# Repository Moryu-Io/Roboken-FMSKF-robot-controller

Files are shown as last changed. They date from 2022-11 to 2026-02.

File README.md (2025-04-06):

# Roboken-FMSKF-robot-controller
## 概要
Teensy4.1を使用した新ROBO-剣出場ロボット[Quinque](https://www.robo-one.com/rankings/view/1127)のHW制御統括マイコンFW  
主な役割は以下
- Ethernet経由Micro-ROSで、ロボット全体を統括する上位LinuxPCと情報をやり取りする
- 5軸ロボットアームへの指示、情報収集
- 4輪メカナムホイールモータの速度制御
- 距離センサを用いて床や相手ロボットの検知を簡易的に行う
- 相手ロボット認識用のカメラをPan/Tiltさせるサーボモータを制御

## SW構成(src内)
すべてFreeRTOSのタスクベースでフォルダ分け

| フォルダ名 | 説明 |
| --- | --- |
|RobotManager|Ethernet経由Micro-ROSで、上位のLinuxPCと情報をやり取りしながらHW行動を決定するモジュール|
|ArmDrive|5軸ロボットアームの制御を行う。各関節ごとに[ドライバ](https://github.com/Moryu-Io/Bldc_Servo_Driver_Prj)内で位置/トルク制御を行うため、このモジュールでは指示を統括|
|VehicleDrive|4輪メカナムホイールのモータ制御を行う。こちらはDJIのM2006,C610を使用しており、ドライバ内でのトルク制御を行うため、モータの速度制御から上位の指示/制御を統括|
|FloorDetect|競技エリアから落ちないように距離センサで床面をセンシングするモジュール|
|CameraGimbal|カメラをPan/Tiltさせる汎用サーボモータの制御モジュール|
|Logger|Print文をSDカードに保存するためのDebug用モジュール|
|Debug|DebugPrintやRTOSのリソース状況を出力するDebug用モジュール|
|Utility|汎用モジュール。自作の計算処理など|

## 使用ライブラリ
| フォルダ名 | 説明 |
| --- | --- |
|[FreeRTOS-Teensy4](https://github.com/juliandesvignes/FreeRTOS-Teensy4)|RTOS|
|[micro_ros_arduino](https://github.com/micro-ROS/micro_ros_arduino)|Micro-ROS Quinque用のカスタムメッセージを含めてビルドしたものを同梱|
|[IcsClass_V210](https://kondo-robot.com/faq/ics-library-a2)|一部使用している近藤科学製サーボモータ制御用|
|[TsyDMASPI](https://github.com/hideakitai/TsyDMASPI)|IMU用SPIだが現状ほぼ未使用|

# 雑多なメモ
## 新規Msgの追加方法
### msgファイルの作成

`micro_ros_arduino\extras\library_generation\extra_packages`直下にmsgフォルダを作る

[公式チュートリアル](https://micro.ros.org/docs/tutorials/advanced/create_new_type/)に従って、.msgファイルの作成とCMakeLists.txtへの登録を行う

ここには記載がないが、package.xml末尾に以下を追加する必要もある
```
  <build_depend>rosidl_default_generators</build_depend>
  <exec_depend>rosidl_default_runtime</exec_depend>
  <member_of_group>rosidl_interface_packages</member_of_group>
```

### micro_ros_arduinoライブラリを作成する
wsl2にて以下のコマンドを発行
```
sudo service docker start

docker pull microros/micro_ros_static_library_builder:foxy
docker run -it --rm -v $(pwd):/project --env MICROROS_LIBRARY_FOLDER=extras microros/micro_ros_static_library_builder:foxy -p teensy4
```
※2022/05/08 wsl2で上記コマンドでdocker使用時に名前解決ができなくなっていた。原因不明。

[このサイト](https://qiita.com/takkeybook/items/37af683bfb1a4eca6aa2)に従って、`/etc/resolv.conf`に記載のDNSサーバーを変更する

### PC側での準備
通信するPC側では同様のmsg定義フォルダを作成
```
colcon build --symlink-install --packages-up-to interfaces
. install/local_setup.bash
ros2 run micro_ros_agent micro_ros_agent udp4 -p 9999
```

### Micro-ROSテスト方法memo
- topic
```
ros2 topic echo /VehicleInfo
```

- service
```
ros2 service call /ProcStatus interfaces/srv/ProcStatus "{id: 1}"
```

## FreeRTOS

こちらのリポジトリをベースに、libフォルダに格納
https://github.com/juliandesvignes/FreeRTOS-Teensy4

変更点
* heap3からheap4に
    * heap3はC言語のmallocなどのラッパだが、Teensyduinoではmallocで確保されるのは通常RAM。
    * heap4でucHeapをTCMに配置することで高速性を担保
* 別途configファイルを設定

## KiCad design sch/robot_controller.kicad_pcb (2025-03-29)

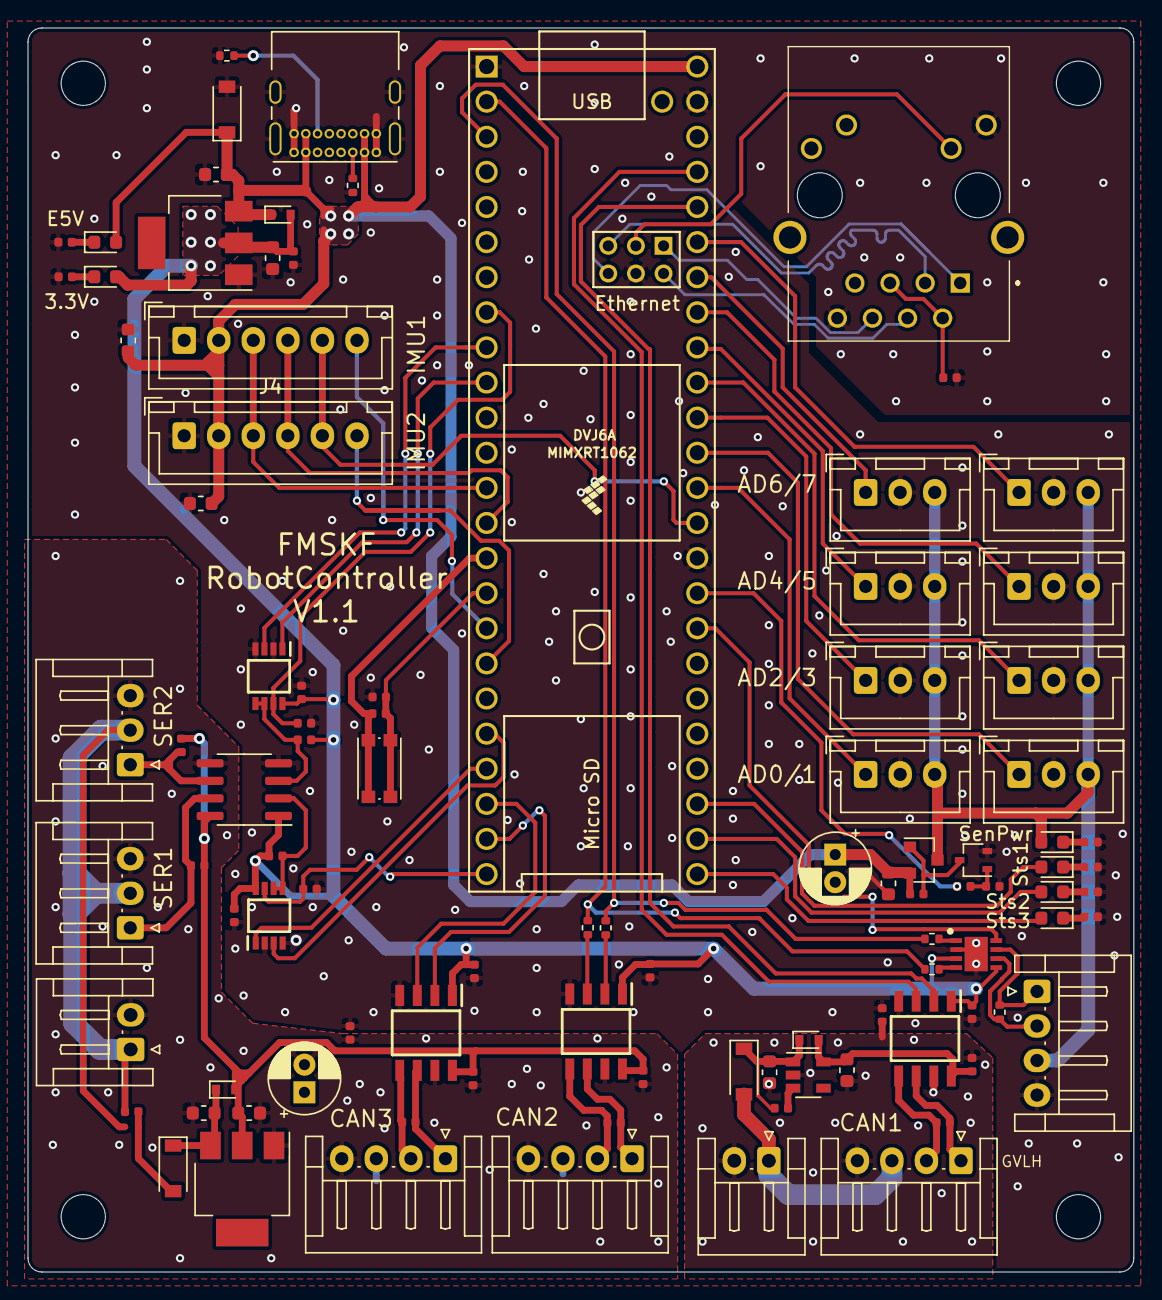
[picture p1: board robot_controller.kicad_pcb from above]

Board: 2 copper layers, 80.0 x 90.0 mm, 102 parts (0 on the bottom side), 78 nets.

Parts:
C1, C3, C17, C19, C21: 1u; C_0603_1608Metric
C2, C4, C8, C11, C12, C13, C14, C15, C16, C18, C20: 0.1u; C_0402_1005Metric
C5, C6, C7, C22: 10u; C_0603_1608Metric
C24, C25: 47u; CP_Radial_D5.0mm_P2.00mm
D1, D7, D11: PMEG6010CEGWJ; D_SOD-123
D2, D4, D6, D13, D14, D15: LED; LED_0603_1608Metric
D5, D9, D12: RB5105SM-40T; D_SOD-523
H1, H2, H3, H4: MountingHole; MountingHole_3.2mm_M3
IC1, IC2, IC5: ISO1044BDR; SOIC127P600X175-8N
IC3, IC4: 74LVC2G125DP,125; SOP65P400X110-8N
IC6: TLT9251VLEXUMA1; SON65P300X300X110-9N
J1: USB_C_Receptacle_USB2.0; USB_C_Receptacle_GCT_USB4085
J2, J4: Conn_01x06; JST_XH_B6B-XH-A_1x06_P2.50mm_Vertical
J3: RJ45_LED; J1B1211CCD
J5, J6, J7, J8, J9, J10, J11, J12: Conn_01x03; JST_XH_B3B-XH-A_1x03_P2.50mm_Vertical
J13, J15, J17, J18: Conn_01x04; JST_EH_S4B-EH_1x04_P2.50mm_Horizontal
J16, J20: Conn_01x02; JST_EH_S2B-EH_1x02_P2.50mm_Horizontal
J19, J21: Conn_01x03; JST_EH_S3B-EH_1x03_P2.50mm_Horizontal
Q2: 2SC4116; SOT-323_SC-70
Q4: IRLML6402; SOT-23
R1, R10, R12, R14, R23, R24, R27, R28, R31, R36, R37: 10k; R_0402_1005Metric
R2, R5: 5.1k; R_0402_1005Metric
R3, R16, R22, R38, R39, R40: 1k; R_0402_1005Metric
R4, R6, R8, R9, R25, R26, R33: 0; R_0402_1005Metric
R7, R29, R30, R35: 60; R_0402_1005Metric
SW1: SW_SPST; SW_Push_1P1T_NO_CK_KMR2
U1: Teensy4.1; Teensy41simple_onlyeth
U2: AZ1117-3.3; SOT-223
U3: ISO1540; SOIC-8_3.9x4.9mm_P1.27mm
U4: NCP718xSN500; SOT-23-5
U5: LD1117S50TR_SOT223; SOT-223-3_TabPin2

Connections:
+3.3VP: C7.1, C8.1, C11.1, C12.1, C13.1, C14.1, C18.1, D5.2, D6.2, IC1.1, IC2.1, IC3.8, IC4.8, IC5.1, IC6.3, IC6.5, R27.1, R28.1, U2.2, U3.1
+3V3: C4.1, SW1.1, U1.15, U1.46
+5VL: C1.1, C3.1, C5.1, C6.1, C24.1, D1.1, D2.2, D5.1, J1.A4, J1.A9, J1.B4, J1.B9, J2.2, J4.2, Q4.2, R12.1, U1.48, U2.3
/5V_P1: C15.1, C19.1, D9.2, IC5.8, U4.5
/5V_P3: C16.1, C20.1, C22.2, D12.2, IC1.8, IC2.8, R36.1, R37.1, U3.8, U5.2
/CAN1_H: IC5.6, J15.1, R29.1
/CAN1_L: IC5.5, J15.2, R29.2
/CAN1_RX: IC5.3, U1.45
/CAN1_TX: IC5.2, U1.44
/CAN2_H: IC1.6, J18.1, R35.1
/CAN2_L: IC1.5, J18.2, R35.2
/CAN2_RX: R6.1, R9.1, U1.2
/CAN2_TX: R4.1, R8.1, U1.3
/CAN3_H: IC2.6, J17.1, R30.1
/CAN3_L: IC2.5, J17.2, R30.2
/CAN3_RX: IC2.3, U1.22
/CAN3_TX: IC2.2, U1.23
/ETH_LED: J3.10, U1.61
/ETH_RX+: J3.6, U1.60
/ETH_RX-: J3.4, U1.65
/ETH_TX+: J3.1, U1.63
/ETH_TX-: J3.3, U1.62
/GND_P1: C15.2, C17.2, C19.2, IC5.7, J15.4, J16.2, R25.2, U4.2
/GND_P3: C16.2, C20.2, C21.1, C22.1, C25.2, IC1.7, IC2.7, J17.4, J18.4, J19.3, J20.2, J21.3, R26.2, U3.5, U5.1
/IMU_SPI_CS1: J2.6, U1.17
/IMU_SPI_CS2: J4.6, U1.18
/IMU_SPI_MISO: J2.4, J4.4, U1.14
/IMU_SPI_MOSI: J2.3, J4.3, U1.13
/IMU_SPI_SCK: J2.5, J4.5, U1.35
/SERIAL2_EN: IC4.7, R24.1, U1.8
/SERIAL2_RX: IC4.3, U1.9
/SERIAL2_TX: IC4.1, U1.10
/SERIAL7_EN: IC3.7, R23.1, U1.24
/SERIAL7_RX: IC3.3, U1.20
/SERIAL7_TX: IC3.1, U1.21
/TTL_SERIAL1: J19.1, R37.2, U3.7
/TTL_SERIAL2: J21.1, R36.2, U3.6
/USER_SWITCH: C4.2, R1.2, SW1.2, U1.16
/VCC_P1: D7.2, J15.3, J16.1
/VCC_P3: C25.1, J17.3, J18.3, J19.2, J20.1, J21.2, R33.1
/WALLTOF_CAN_EN: IC6.8, U1.32
/WALL_AD0: J5.1, U1.36
/WALL_AD1: J6.1, U1.37
/WALL_AD2: J7.1, U1.38
/WALL_AD3: J8.1, U1.39
/WALL_AD4: J9.1, U1.40
/WALL_AD5: J10.1, U1.41
/WALL_AD6: J11.1, U1.42
/WALL_AD7: J12.1, U1.43
/WALL_PWR: R10.1, U1.33
/WALL_VCC: D4.2, J5.3, J6.3, J7.3, J8.3, J9.3, J10.3, J11.3, J12.3, J13.3, Q4.3
GND: C1.2, C2.2, C3.2, C5.2, C6.2, C7.2, C8.2, C11.2, C12.2, C13.2, C14.2, C18.2, C24.2, D1.2, IC1.4, IC2.4, IC3.2, IC3.4, IC4.2, IC4.4, IC5.4, IC6.2, IC6.9, J1.A1, J1.A12, J1.B1, J1.B12, J1.S1, J2.1, J3.8, J3.9, J4.1, J5.2, J6.2, J7.2, J8.2, J9.2, J10.2, J11.2, J12.2, J13.4, Q2.2, R1.1, R2.2, R3.2, R5.1, R14.2, R16.2, R22.2, R23.2, R24.2, R25.1, R26.1, R38.2, R39.2, R40.2, U1.1, U1.34, U1.47, U1.64, U2.1, U3.4
unnamed: C2.1, J3.2, J3.5
unnamed: C17.1, D7.1, D9.1, R31.1, U4.1
unnamed: C21.2, D11.1, D12.1, U5.3
unnamed: D2.1, R3.1
unnamed: D4.1, R16.1
unnamed: D6.1, R22.1
unnamed: D11.2, R33.2
unnamed: D13.1, R38.1
unnamed: D13.2, U1.25
unnamed: D14.1, R39.1
unnamed: D14.2, U1.26
unnamed: D15.1, R40.1
unnamed: D15.2, U1.27
unnamed: IC1.2, R8.2
unnamed: IC1.3, R9.2
unnamed: IC3.5, IC3.6, R27.2, U3.2
unnamed: IC4.5, IC4.6, R28.2, U3.3
unnamed: IC6.1, R4.2
unnamed: IC6.4, R6.2
unnamed: IC6.6, J13.2, R7.2
unnamed: IC6.7, J13.1, R7.1
unnamed: J1.A5, R2.1
unnamed: J1.B5, R5.2
unnamed: Q2.1, R10.2, R14.1
unnamed: Q2.3, Q4.1, R12.2
unnamed: R31.2, U4.3

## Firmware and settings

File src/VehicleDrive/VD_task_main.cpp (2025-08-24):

// RTOS
#include <FreeRTOS_TEENSY4.h>
#include <message_buffer.h>

// Arduinoライブラリ
#include <TsyDMASPI.h>
#include <math.h>

// ローカル
#include "VD_can_controller.hpp"
#include "VD_imu_if_mpu6500.hpp"
#include "VD_motor_if_m2006.hpp"
#include "VD_task_main.hpp"
#include "VD_vehicle_controller.hpp"
#include "../Utility/util_mymath.hpp"
#include "../Imu/imu_task_main.hpp"
#include "global_config.hpp"

namespace VDT {

// ローカルパラメータ定義
constexpr uint32_t U32_VEHICLE_CTRL_FREQ_HZ           = 1000;
constexpr uint32_t U32_VD_TASK_CTRL_FREQ_HZ           = 100;
constexpr float    FL_VEHICLE_DEFAULT_SPEED_MMPS      = 200;
constexpr float    FL_VEHICLE_DEFAULT_ROT_SPEED_RADPS = 2.0f * M_PI / 1.0f;
constexpr float    FL_VEHICLE_LIMIT_SPEED_MMPS        = 400;
constexpr float    FL_VEHICLE_LIMIT_ROT_SPEED_RADPS   = 6.0f * M_PI / 1.0f;

const Direction C_ACCEL_MAX_MOVE = {
    .x  = 1000.0f,
    .y  = 1000.0f,
    .th = 30.0f,
};
const Direction C_JERK_MAX_MOVE = {
    .x  = 10000.0f,
    .y  = 10000.0f,
    .th = 300.0f,
};
const Direction C_ACCEL_MAX_STOP = {
    .x  = 2000.0f,
    .y  = 2000.0f,
    .th = 70.0f,
};
const Direction C_JERK_MAX_STOP = {
    .x  = 30000.0f,
    .y  = 30000.0f,
    .th = 1000.0f,
};

// Peripheral設定
constexpr uint8_t U8_IMU1_CS_PIN = 37;
constexpr uint8_t U8_IMU2_CS_PIN = 36;

IntervalTimer canTxTimer; //タイマー割り込み

// デバイス設定
class IMU1 : public IMU_IF_MPU6500 {
public:
  void init() override {
    TsyDMASPI0.begin(U8_IMU1_CS_PIN, SPISettings(1000000, MSBFIRST, SPI_MODE3), true);
    LSBtoG     = 1.0f / 16834.0f;
    LSBtoRADPS = 3.141592f / (180.0f * 131.0f);
  }

protected:
  void kickSpiDma(uint8_t size) {
    TsyDMASPI0.queue(u8_tx_buf, u8_rx_buf, (size_t)size, U8_IMU1_CS_PIN);
  };
  bool isCompSpiDmaQueue() {
    return TsyDMASPI0.remained() == 0;
  };
};

// モータIF
MOTOR_IF_M2006 FL_motor(1);
MOTOR_IF_M2006 BL_motor(1);
MOTOR_IF_M2006 BR_motor(-1);
MOTOR_IF_M2006 FR_motor(-1);

// モータ用CAN IF
CAN_CTRL<CAN1> M_CAN;
template <>
MOTOR_IF_M2006 *CAN_CTRL<CAN1>::p_motor_if[4] = {&FL_motor, &BL_motor, &BR_motor, &FR_motor};

// モータ制御コントローラ
UTIL::FF_PI_D FL_m_ctrl((float)U32_VD_TASK_CTRL_FREQ_HZ, 0.0075f, 0.02f, 0.01f, 0.0f, 0.5f, 10.0f);
UTIL::FF_PI_D BL_m_ctrl((float)U32_VD_TASK_CTRL_FREQ_HZ, 0.0075f, 0.02f, 0.01f, 0.0f, 0.5f, 10.0f);
UTIL::FF_PI_D BR_m_ctrl((float)U32_VD_TASK_CTRL_FREQ_HZ, 0.0075f, 0.02f, 0.01f, 0.0f, 0.5f, 10.0f);
UTIL::FF_PI_D FR_m_ctrl((float)U32_VD_TASK_CTRL_FREQ_HZ, 0.0075f, 0.02f, 0.01f, 0.0f, 0.5f, 10.0f);

// IMU
static IMU1 imu1;

// 車体速度補間用
UTIL::VelInterpConstJerk VelIntpConstJerk_Xdir(1.0f / (float)U32_VEHICLE_CTRL_FREQ_HZ);
UTIL::VelInterpConstJerk VelIntpConstJerk_Ydir(1.0f / (float)U32_VEHICLE_CTRL_FREQ_HZ);
UTIL::VelInterpConstJerk VelIntpConstJerk_Tdir(1.0f / (float)U32_VEHICLE_CTRL_FREQ_HZ);

// Vehicleクラス用のパーツ
VEHICLE_CTRL::Parts vhcl_parts = {
    .p_imu        = &imu1,
    .p_vel_interp = {&VelIntpConstJerk_Xdir, &VelIntpConstJerk_Ydir, &VelIntpConstJerk_Tdir},
    .p_motor      = {&FL_motor, &BL_motor, &BR_motor, &FR_motor},
    .p_ctrl       = {&FL_m_ctrl, &BL_m_ctrl, &BR_m_ctrl, &FR_m_ctrl},
};

// インスタンス
static VEHICLE_CTRL vhclCtrl(vhcl_parts);

// RTOS メッセージ
MessageBufferHandle_t p_MsgBufReq;
MSG_REQ               msgReq;

// 移動時間管理用変数類
uint32_t U32_MOVE_TIME_CNT_ORDER = 0;   // 指示された移動時間[カウント]

void can_tx_routine_intr();

static float speed_limit(uint32_t u32_spd){
  if(u32_spd == 0) {
    return (float)FL_VEHICLE_DEFAULT_SPEED_MMPS;
  } else {
    return (float)((u32_spd > FL_VEHICLE_LIMIT_SPEED_MMPS) ? FL_VEHICLE_LIMIT_SPEED_MMPS : u32_spd);
  }
}

static void speed_limit_xy(float fl_tgt_spdx, float fl_tgt_spdy, float& fl_rtn_spdx, float& fl_rtn_spdy){
  float spd_len_org = UTIL::mymath::sqrtf(fl_tgt_spdx * fl_tgt_spdx + fl_tgt_spdy * fl_tgt_spdy);
  float spd_len_lim = (spd_len_org > FL_VEHICLE_LIMIT_SPEED_MMPS) ? FL_VEHICLE_LIMIT_SPEED_MMPS : spd_len_org;
  if(spd_len_org == 0){
    fl_rtn_spdx = 0;
    fl_rtn_spdy = 0;
  }else{
    fl_rtn_spdx = fl_tgt_spdx * spd_len_lim / spd_len_org;
    fl_rtn_spdy = fl_tgt_spdy * spd_len_lim / spd_len_org;
  }
}

static float speed_limit_rot(float fl_tgt_spdrot){
    return (float)((fl_tgt_spdrot > FL_VEHICLE_LIMIT_ROT_SPEED_RADPS) ? FL_VEHICLE_LIMIT_ROT_SPEED_RADPS 
                 :((fl_tgt_spdrot < -FL_VEHICLE_LIMIT_ROT_SPEED_RADPS) ? -FL_VEHICLE_LIMIT_ROT_SPEED_RADPS : fl_tgt_spdrot));
}

static float rot_speed_limit(uint32_t u32_spd){
  if(u32_spd == 0) {
    return (float)FL_VEHICLE_DEFAULT_ROT_SPEED_RADPS;
  } else {
    float fl_spd = (float)u32_spd * 0.1; // 10されて受け渡される
    return (float)((fl_spd > FL_VEHICLE_LIMIT_ROT_SPEED_RADPS) ? FL_VEHICLE_LIMIT_ROT_SPEED_RADPS : fl_spd);
  }
}


void prepare_task() {
  p_MsgBufReq = xMessageBufferCreate(VDT_MSG_REQ_BUFFER_SIZE * sizeof(MSG_REQ));

  FL_m_ctrl.set_FF_limit(1.0f);
  BL_m_ctrl.set_FF_limit(1.0f);
  BR_m_ctrl.set_FF_limit(1.0f);
  FR_m_ctrl.set_FF_limit(1.0f);

  imu1.init();
  M_CAN.init();

  canTxTimer.begin(can_tx_routine_intr, U32_VEHICLE_CTRL_FREQ_HZ);
}

void main(void *params) {
  uint32_t debug_counter = 0;
  uint32_t loop_tick     = (int)configTICK_RATE_HZ / U32_VD_TASK_CTRL_FREQ_HZ;

  auto xLastWakeTime = xTaskGetTickCount();
  while(1) {
    vTaskDelayUntil(&xLastWakeTime, loop_tick);
    DEBUG_PRINT_PRC_START(VDT_MAIN);

    /* Msg処理 */
    if(xMessageBufferReceive(p_MsgBufReq, (void *)&msgReq, sizeof(MSG_REQ), 0) == sizeof(MSG_REQ)) {
      switch(msgReq.common.MsgId) {
      case REQ_MOVE_DIR: {
        DEBUG_PRINT_VDT("[VDT]MOVE_DIR:%d\n", msgReq.move_dir.u32_cmd);

        float speed = 0;
        U32_MOVE_TIME_CNT_ORDER = msgReq.move_dir.u32_time_ms * U32_VD_TASK_CTRL_FREQ_HZ / 1000 + 1;

        /* 指示方向に応じて必要な要素を埋める */
        Direction move_dir = {};
        Direction accl_dir = {};
        Direction jerk_dir = {};
        switch(msgReq.move_dir.u32_cmd) {
        case GO_FORWARD:
          speed = speed_limit(msgReq.move_dir.u32_speed);
          move_dir.x  = (float)speed;
          move_dir.y  = 0;
          move_dir.th = 0;
          accl_dir    = C_ACCEL_MAX_MOVE;
          jerk_dir    = C_JERK_MAX_MOVE;
          break;
        case GO_BACK:
          speed = speed_limit(msgReq.move_dir.u32_speed);
          move_dir.x  = -(float)speed;
          move_dir.y  = 0;
          move_dir.th = 0;
          accl_dir    = C_ACCEL_MAX_MOVE;
          jerk_dir    = C_JERK_MAX_MOVE;
          break;
        case GO_RIGHT:
          speed = speed_limit(msgReq.move_dir.u32_speed);
          move_dir.x  = 0;
          move_dir.y  = -(float)speed;
          move_dir.th = 0;
          accl_dir    = C_ACCEL_MAX_MOVE;
          jerk_dir    = C_JERK_MAX_MOVE;
          break;
        case GO_LEFT:
          speed = speed_limit(msgReq.move_dir.u32_speed);
          move_dir.x  = 0;
          move_dir.y  = (float)speed;
          move_dir.th = 0;
          accl_dir    = C_ACCEL_MAX_MOVE;
          jerk_dir    = C_JERK_MAX_MOVE;
          break;
        case GO_RIGHT_FORWARD:
          speed = speed_limit(msgReq.move_dir.u32_speed);
          move_dir.x  = (float)speed * sqrtf(2) * 0.5f;
          move_dir.y  = -(float)speed * sqrtf(2) * 0.5f;
          move_dir.th = 0;
          accl_dir    = C_ACCEL_MAX_MOVE;
          jerk_dir    = C_JERK_MAX_MOVE;
          break;
        case GO_LEFT_FORWARD:
          speed = speed_limit(msgReq.move_dir.u32_speed);
          move_dir.x  = (float)speed * sqrtf(2) * 0.5f;
          move_dir.y  = (float)speed * sqrtf(2) * 0.5f;
          move_dir.th = 0;
          accl_dir    = C_ACCEL_MAX_MOVE;
          jerk_dir    = C_JERK_MAX_MOVE;
          break;
        case GO_RIGHT_BACK:
          speed = speed_limit(msgReq.move_dir.u32_speed);
          move_dir.x  = -(float)speed * sqrtf(2) * 0.5f;
          move_dir.y  = -(float)speed * sqrtf(2) * 0.5f;
          move_dir.th = 0;
          accl_dir    = C_ACCEL_MAX_MOVE;
          jerk_dir    = C_JERK_MAX_MOVE;
          break;
        case GO_LEFT_BACK:
          speed = speed_limit(msgReq.move_dir.u32_speed);
          move_dir.x  = -(float)speed * sqrtf(2) * 0.5f;
          move_dir.y  = (float)speed * sqrtf(2) * 0.5f;
          move_dir.th = 0;
          accl_dir    = C_ACCEL_MAX_MOVE;
          jerk_dir    = C_JERK_MAX_MOVE;
          break;
        case ROT_RIGHT:
          speed = rot_speed_limit(msgReq.move_dir.u32_speed);
          move_dir.x  = 0;
          move_dir.y  = 0;
          move_dir.th = -speed;
          accl_dir    = C_ACCEL_MAX_MOVE;
          jerk_dir    = C_JERK_MAX_MOVE;
          break;
        case ROT_LEFT:
          speed = rot_speed_limit(msgReq.move_dir.u32_speed);
          move_dir.x  = 0;
          move_dir.y  = 0;
          move_dir.th = speed;
          accl_dir    = C_ACCEL_MAX_MOVE;
          jerk_dir    = C_JERK_MAX_MOVE;
          break;
        case MOVE_STOP:
        default:
          move_dir.x  = 0;
          move_dir.y  = 0;
          move_dir.th = 0;
          accl_dir    = C_ACCEL_MAX_STOP;
          jerk_dir    = C_JERK_MAX_STOP;
          break;
        }
        vhclCtrl.start();
        vhclCtrl.set_target_vel(move_dir, accl_dir, jerk_dir);
      } break;  // REQ_MOVE_DIR
      case REQ_MOVE_CONT_DIR: {
        DEBUG_PRINT_STR_VDT("[VDT]MOVE_CONT_DIR\n");
        U32_MOVE_TIME_CNT_ORDER = msgReq.move_cont_dir.u32_time_ms * U32_VD_TASK_CTRL_FREQ_HZ / 1000 + 1;

        float speed_x = 0;
        float speed_y = 0;
        speed_limit_xy(msgReq.move_cont_dir.fl_vel_x_mmps, msgReq.move_cont_dir.fl_vel_y_mmps,
                       speed_x, speed_y);
        float speed_th = speed_limit_rot(msgReq.move_cont_dir.fl_vel_th_radps);

        Direction move_dir = {speed_x, speed_y, speed_th};
        vhclCtrl.start();
        vhclCtrl.set_target_vel(move_dir, (VDT::Direction&)C_ACCEL_MAX_MOVE, (VDT::Direction&)C_JERK_MAX_MOVE);
      } break;  // REQ_MOVE_CONT_DIR
      default:
        break;
      }


    }

    /* 指定時間動いたら止まる指示を出すところ */
    if(U32_MOVE_TIME_CNT_ORDER > 1){
      U32_MOVE_TIME_CNT_ORDER--;
    } else if(U32_MOVE_TIME_CNT_ORDER == 1){
      /* 停止指示 */
      Direction move_dir = {};
      Direction accl_dir = {};
      Direction jerk_dir = {};
      move_dir.x  = 0;
      move_dir.y  = 0;
      move_dir.th = 0;
      accl_dir    = C_ACCEL_MAX_STOP;
      jerk_dir    = C_JERK_MAX_STOP;
      vhclCtrl.start();
      vhclCtrl.set_target_vel(move_dir, accl_dir, jerk_dir);
      U32_MOVE_TIME_CNT_ORDER = 0;
    } else {
      /* 0 */
    }

    /* 車体制御Routine */
    // vhclCtrl.update();  // Timer割り込みで1kHz周期で計算する

    /* CAN Routine */
    // M_CAN.events(); // 多分不要
    // M_CAN.tx_routine();  // Timer割り込みで1kHz周期で送信する

    /* 以下、デバッグ用 */
    if(debug_counter == 2) {
      // Direction vhcl_pos;
      // vhclCtrl.get_vehicle_pos_mm_latest(vhcl_pos);
      //  DEBUG_PRINT_VDT_MOTOR("[VDT]%d,%d,%d\n", (int)vhcl_pos.x, (int)vhcl_pos.y, (int)vhcl_pos.th);
      Direction vhcl_vel;
      vhclCtrl.get_vehicle_vel_tgt_mmps_latest(vhcl_vel);
      // DEBUG_PRINT_VDT_MOTOR("[VDT]%d,%d,%d\n", (int)vhcl_vel.x, (int)vhcl_vel.y, (int)vhcl_vel.th);

      /* 車体モータデバッグ用 削除禁止 */
      int _fl_nowvel = FL_m_ctrl.get_now_val();
      int _bl_nowvel = BL_m_ctrl.get_now_val();
      int _br_nowvel = BR_m_ctrl.get_now_val();
      int _fr_nowvel = FR_m_ctrl.get_now_val();
      int _fl_tgtvel = FL_m_ctrl.get_target();
      int _bl_tgtvel = BL_m_ctrl.get_target();
      int _br_tgtvel = BR_m_ctrl.get_target();
      int _fr_tgtvel = FR_m_ctrl.get_target();
      //DEBUG_PRINT_VDT_MOTOR("[VDT],%d,%d,%d,%d,%d,%d,%d,%d,%d,%d,%d,%d\n", _fl_tgtvel, _fl_nowvel, FL_motor.get_rawCurr_tgt() //
      //                      ,
      //                      _bl_tgtvel, _bl_nowvel, BL_motor.get_rawCurr_tgt() //
      //                      ,
      //                      _br_tgtvel, _br_nowvel, BR_motor.get_rawCurr_tgt() //
      //                      ,
      //                      _fr_tgtvel, _fr_nowvel, FR_motor.get_rawCurr_tgt());
      //DEBUG_PRINT_VDT_MOTOR("[VDT],%d,%d,%d,%d,%d,%d,%d,%d,%d,%d,%d,%d\n", _fl_tgtvel, _fl_nowvel, FL_motor.get_rawCurr_tgt());
      debug_counter = 0;
    } else {
      debug_counter++;
    }

    DEBUG_PRINT_PRC_FINISH(VDT_MAIN);
  }
}

void can_tx_routine_intr() {
  DEBUG_PRINT_PRC_START(VDT_CAN_TX);
  vhclCtrl.set_now_yaw_world(UTIL::mymath::deg2rad(IMT::get_status_now_yaw()));
  vhclCtrl.update();
  M_CAN.tx_routine();
  DEBUG_PRINT_PRC_FINISH(VDT_CAN_TX);
}

void get_status_now_vehicle_pos_world(float &_px, float &_py, float &_pr){
  Direction _pos = {};
  vhclCtrl.get_vehicle_pos_m_latest(_pos);
  _px = _pos.x;
  _py = _pos.y;
  _pr = _pos.th;
}

void get_status_now_vehicle_vel_world(float &_vx, float &_vy, float &_vr){
  _vx = 0;
  _vy = 0;
  _vr = 0;

}

void get_status_now_vehicle_vel(float &_vx, float &_vy, float &_vr){
  Direction _vdir = {};
  vhclCtrl.get_vehicle_vel_mmps_latest(_vdir);
  _vx = _vdir.x;
  _vy = _vdir.y;
  _vr = _vdir.th;
}

void send_req_msg(MSG_REQ *_msg) {
  xMessageBufferSend(p_MsgBufReq, (void *)_msg, sizeof(MSG_REQ), 0);
}
}; // namespace VDT

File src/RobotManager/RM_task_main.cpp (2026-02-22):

// RTOS
#include <FreeRTOS_TEENSY4.h>

#include <geometry_msgs/msg/twist.h>
#include <interfaces/msg/arm_info.h>
#include <interfaces/msg/cam_angle_order.h>
#include <interfaces/msg/command.h>
#include <interfaces/msg/mecanum_command.h>
#include <interfaces/msg/mecanum_cont_order.h>
#include <interfaces/msg/time_angle.h>
#include <interfaces/msg/vehicle_info.h>
#include <interfaces/srv/proc_status.h>
#include <micro_ros_arduino.h>
#include <rcl/error_handling.h>
#include <rcl/rcl.h>
#include <rclc/executor.h>
#include <rclc/rclc.h>
#include <std_msgs/msg/int32.h>
#include <rosidl_runtime_c/string_functions.h>
#include <stdio.h>

#include "../ArmDrive/AD_task_main.hpp"
#include "../CameraGimbal/CG_task_main.hpp"
#include "../FloorDetect/FD_task_main.hpp"
#include "../Utility/util_led.hpp"
#include "../Utility/util_mymath.hpp"
#include "../VehicleDrive/VD_task_main.hpp"
#include "../Imu/imu_task_main.hpp"

// Local status
/* Ethernet */
bool is_ethernet_init_successful = false;
bool is_microros_init_successful = false;
enum ConnectionStatus{
  WAITING_AGENT,
  AVAILABLE_AGENT,
  CONNECTED,
  DISCONNECTED,
  UNKNOWN,
};
ConnectionStatus UROS_AGENT_STATUS = WAITING_AGENT;
uint32_t U32_UROS_PING_COUNTER_MATCH = 15;  // この回数に一回、Pingを打つ
uint32_t U32_UROS_PING_COUNTER       = 0; // Pingを打つまでのカウンター

/* CommandIF */
enum CmdStatus {
  RELAX       = 0,
  MOVE_READY  = 1,
  MOVE_START  = 2,
  QUIT_PG     = 3,
  INIT        = 4,
  HW_DEBUG    = 5,
  DUUMY6      = 6,
  DUUMY7      = 7,
  DUUMY8      = 8,
  DUUMY9      = 9,
  SWITCH_FLOOR_SENSOR = 10,
  UNKNOWN_CMD = 0xFF,
};
CmdStatus NOW_CMD_STATUS = CmdStatus::RELAX;

uint32_t     U32_MCN_NO_CMD_CNT            = 0;
uint32_t     U32_MCN_NO_CMD_STOP_THRE      = 200;
uint32_t     U32_MCN_WALL_LEAVE_TIME_MS    = 200; // 壁から離れる時の駆動時間
uint32_t     U32_MCN_WALL_LEAVE_SPEED_MMPS = 100; // 壁から離れる時の速度
bool         IS_MCN_CMD_UPDATED            = false;
uint8_t      U8_VDT_MSG_BUF_WRITE          = 0;   // 現在書き込み対象のBuffer面
VDT::MSG_REQ vdt_msg_buf_[2];
bool         IS_IGNORE_FLOOR_DETECTION = false; // 床検知を無視するかどうかのフラグ

typedef union{
  uint32_t val;
  struct{
    uint32_t wall_abort_vdt_x_p:1;  // 壁起因でX+方向車両駆動リクエストが棄却されたかどうか
    uint32_t wall_abort_vdt_x_m:1;  // 壁起因でX-方向車両駆動リクエストが棄却されたかどうか
    uint32_t wall_abort_vdt_y_p:1;  // 壁起因でY+方向車両駆動リクエストが棄却されたかどうか
    uint32_t wall_abort_vdt_y_m:1;  // 壁起因でY-方向車両駆動リクエストが棄却されたかどうか
    uint32_t wall_abort_vdt_r_p:1;  // 壁起因でR+方向車両駆動リクエストが棄却されたかどうか
    uint32_t wall_abort_vdt_r_m:1;  // 壁起因でR-方向車両駆動リクエストが棄却されたかどうか
    uint32_t resv_6_7:2;            // resrv
    uint32_t fllr_abort_vdt_x_p:1;  // 床起因でX+方向車両駆動リクエストが棄却されたかどうか(Dir)
    uint32_t fllr_abort_vdt_x_m:1;  // 床起因でX-方向車両駆動リクエストが棄却されたかどうか(Dir)
    uint32_t fllr_abort_vdt_y_p:1;  // 床起因でY+方向車両駆動リクエストが棄却されたかどうか(Dir)
    uint32_t fllr_abort_vdt_y_m:1;  // 床起因でY-方向車両駆動リクエストが棄却されたかどうか(Dir)
    uint32_t fllr_abort_vdt_r_p:1;  // 床起因でR+方向車両駆動リクエストが棄却されたかどうか(Dir)
    uint32_t fllr_abort_vdt_r_m:1;  // 床起因でR-方向車両駆動リクエストが棄却されたかどうか(Dir)
    uint32_t resv_14_15:2;         // resrv
    uint32_t fllr_abort_vdt_cont_trans_dir:1;  // 床起因で連続駆動進行方向車両駆動リクエストが棄却されたかどうか
    uint32_t fllr_abort_vdt_cont_rot_dir:1;    // 床起因で連続駆動回転方向車両駆動リクエストが棄却されたかどうか
    uint32_t resv_18_31:14;         // resrv
  }bit;
}VDT_REQ_ABORT;
VDT_REQ_ABORT vdt_abort = {};

// publisher
rcl_publisher_t              pb_vchlInfo;
rcl_publisher_t              pb_ArmInfo;
interfaces__msg__VehicleInfo msg_pb_vhclInfo;
interfaces__msg__ArmInfo     msg_pb_armInfo;

uint8_t U8_PUB_PHASE = 0;

// Buffer for ArmInfo
static constexpr uint8_t U8_ARMANGLE_BUF_LEN = 5;
float fl_ArmAngThetaBuffer[U8_ARMANGLE_BUF_LEN] = {};

// subscriber
rcl_subscription_t              sb_mcnmCmd;
rcl_subscription_t              sb_mcnmContOdr;
rcl_subscription_t              sb_mcnmCmdVel;
rcl_subscription_t              sb_tmAngle;
rcl_subscription_t              sb_cmd;
rcl_subscription_t              sb_camAngOdr;
interfaces__msg__MecanumCommand   msg_sb_mcnmCmd;
interfaces__msg__MecanumContOrder msg_sb_mcnmContOdr;
geometry_msgs__msg__Twist         msg_sb_mcnmCmdVel;
interfaces__msg__TimeAngle        msg_sb_tmAngle;
interfaces__msg__Command          msg_sb_cmd;
interfaces__msg__CamAngleOrder    msg_sb_camAngOdr;

// Buffer for TimeAngle
static constexpr uint8_t U8_TIMEANGLE_BUF_LEN                     = 32;
interfaces__msg__Joint   TimeAngleBuffer[5][U8_TIMEANGLE_BUF_LEN] = {};

// service
rcl_service_t                        srv_proc;
interfaces__srv__ProcStatus_Request  srv_req_procSts;
interfaces__srv__ProcStatus_Response srv_res_procSts;

rclc_executor_t executor;
rclc_executor_t executor_srv;

rclc_support_t  support;
rcl_allocator_t allocator;
rcl_node_t      node;
rcl_timer_t     timer;

#define RCCHECK(fn)                               \
  {                                               \
    rcl_ret_t temp_rc = fn;                       \
    if((temp_rc != RCL_RET_OK)) { error_loop(); } \
  }
#define RCSOFTCHECK(fn)            \
  {                                \
    rcl_ret_t temp_rc = fn;        \
    if((temp_rc != RCL_RET_OK)) {} \
  }

#define toggleRMtaskLED UTIL::toggle_LED1

void error_loop() {
  while(1) {
    toggleRMtaskLED();
    delay(100);
  }
}

void timer_callback(rcl_timer_t *timer, int64_t last_call_time) {
  RCLC_UNUSED(last_call_time);
  if(timer != NULL) {
    RCSOFTCHECK(rcl_publish(&pb_vchlInfo, &msg_pb_vhclInfo, NULL));
    msg_pb_vhclInfo.pos.x++;
    msg_pb_vhclInfo.pos.y--;
    msg_pb_vhclInfo.pos.theta += 0.1f;
  }
}
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

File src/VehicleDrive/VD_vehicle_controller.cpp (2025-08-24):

#include "VD_vehicle_controller.hpp"
#include "../Utility/util_mymath.hpp"

namespace VDT {

void VEHICLE_CTRL::update() {
  /* IMUとの通信をKick */
  // parts_.p_imu->kickCom();

  /* 各モータの回転情報を取得 */
  MOTOR_IF_M2006::Status m_sts[M_Place::Num] = {};
  parts_.p_motor[M_Place::FL]->get_status_latest(m_sts[M_Place::FL]);
  parts_.p_motor[M_Place::BL]->get_status_latest(m_sts[M_Place::BL]);
  parts_.p_motor[M_Place::BR]->get_status_latest(m_sts[M_Place::BR]);
  parts_.p_motor[M_Place::FR]->get_status_latest(m_sts[M_Place::FR]);

  /* 各モータ回転速度[rad/s]を取得 */
  float Mvel[M_Place::Num] = {};

#if 1
  Mvel[M_Place::FL] = (float)m_sts[M_Place::FL].s16_rawSpeedRpm * MOTOR_IF_M2006::RPM_TO_RADPS * MOTOR_IF_M2006::GEAR_RATIO_INV;
  Mvel[M_Place::BL] = (float)m_sts[M_Place::BL].s16_rawSpeedRpm * MOTOR_IF_M2006::RPM_TO_RADPS * MOTOR_IF_M2006::GEAR_RATIO_INV;
  Mvel[M_Place::BR] = (float)m_sts[M_Place::BR].s16_rawSpeedRpm * MOTOR_IF_M2006::RPM_TO_RADPS * MOTOR_IF_M2006::GEAR_RATIO_INV;
  Mvel[M_Place::FR] = (float)m_sts[M_Place::FR].s16_rawSpeedRpm * MOTOR_IF_M2006::RPM_TO_RADPS * MOTOR_IF_M2006::GEAR_RATIO_INV;
#else
  Mvel[M_Place::FL] = m_sts[M_Place::FL].flt_SpeedRadPS;
  Mvel[M_Place::BL] = m_sts[M_Place::BL].flt_SpeedRadPS;
  Mvel[M_Place::BR] = m_sts[M_Place::BR].flt_SpeedRadPS;
  Mvel[M_Place::FR] = m_sts[M_Place::FR].flt_SpeedRadPS;
#endif

  /* 車体フレーム/速度[mm/s]に変換 */
  conv_Mdir_to_Vdir(Mvel, now_vhcl_vel_mmps);

  /* 各モータ回転量[rad]を取得 */
  float Mrad[M_Place::Num] = {};
  for(int i=0;i<M_Place::Num;i++){
    Mrad[i] = static_cast<double>(parts_.p_motor[i]->get_rawAngleSum() - s64_rawAngleSumPrev[i])
                * MOTOR_IF_M2006::OUT_RAD_PER_RAW_ANGLE * MOTOR_IF_M2006::GEAR_RATIO_INV;
    s64_rawAngleSumPrev[i] = parts_.p_motor[i]->get_rawAngleSum();
  }
  

  Direction now_vhcl_pos_local = {};
  conv_Mdir_to_Vdir(Mrad, now_vhcl_pos_local);

  float _rad = UTIL::mymath::normalize_rad_0to2pi(now_vhcl_pos_m_.th);
  float _cth = UTIL::mymath::cosf(_rad);
  float _sth = UTIL::mymath::sinf(_rad);
  now_vhcl_pos_m_.x = now_vhcl_pos_m_.x + (now_vhcl_pos_local.x * _cth - now_vhcl_pos_local.y * _sth)*0.001f;
  now_vhcl_pos_m_.y = now_vhcl_pos_m_.y + (now_vhcl_pos_local.x * _sth + now_vhcl_pos_local.y * _cth)*0.001f;

  /* IMU情報取得 */
  // while(!parts_.p_imu->isComComp()) {}
  // parts_.p_imu->getComData(now_imu_data_);

  /* 車体制御計算 */
  float Mvel_tgt[M_Place::Num] = {};
  now_vhcl_vel_tgt_mmps.x      = parts_.p_vel_interp[En_Dir::Dir_X]->update();
  now_vhcl_vel_tgt_mmps.y      = parts_.p_vel_interp[En_Dir::Dir_Y]->update();
  now_vhcl_vel_tgt_mmps.th     = parts_.p_vel_interp[En_Dir::Dir_TH]->update();
  conv_Vdir_to_Mdir(now_vhcl_vel_tgt_mmps, Mvel_tgt);

  /* モータへの指示 */
  if(isPowerOn) {
    /* 速度制御 */
    parts_.p_ctrl[M_Place::FL]->set_target(Mvel_tgt[M_Place::FL] * MOTOR_IF_M2006::GEAR_RATIO);
    parts_.p_ctrl[M_Place::BL]->set_target(Mvel_tgt[M_Place::BL] * MOTOR_IF_M2006::GEAR_RATIO);
    parts_.p_ctrl[M_Place::BR]->set_target(Mvel_tgt[M_Place::BR] * MOTOR_IF_M2006::GEAR_RATIO);
    parts_.p_ctrl[M_Place::FR]->set_target(Mvel_tgt[M_Place::FR] * MOTOR_IF_M2006::GEAR_RATIO);

    /* トルク指示 */
    parts_.p_motor[M_Place::FL]->set_CurrA_tgt(parts_.p_ctrl[M_Place::FL]->update(Mvel[M_Place::FL] * MOTOR_IF_M2006::GEAR_RATIO));
    parts_.p_motor[M_Place::BL]->set_CurrA_tgt(parts_.p_ctrl[M_Place::BL]->update(Mvel[M_Place::BL] * MOTOR_IF_M2006::GEAR_RATIO));
    parts_.p_motor[M_Place::BR]->set_CurrA_tgt(parts_.p_ctrl[M_Place::BR]->update(Mvel[M_Place::BR] * MOTOR_IF_M2006::GEAR_RATIO));
    parts_.p_motor[M_Place::FR]->set_CurrA_tgt(parts_.p_ctrl[M_Place::FR]->update(Mvel[M_Place::FR] * MOTOR_IF_M2006::GEAR_RATIO));

    //DEBUG_PRINT_VDT_MOTOR("[VDT]tgt:%d,%d,%d,%d\n", (int)(Mvel_tgt[M_Place::FL] * MOTOR_IF_M2006::GEAR_RATIO), (int)(Mvel_tgt[M_Place::BL] * MOTOR_IF_M2006::GEAR_RATIO), (int)(Mvel_tgt[M_Place::BR] * MOTOR_IF_M2006::GEAR_RATIO), (int)(Mvel_tgt[M_Place::FR] * MOTOR_IF_M2006::GEAR_RATIO));

    //DEBUG_PRINT_VDT_MOTOR("[VDT]vel:%d,%d,%d,%d\n", (int)Mvel[M_Place::FL], (int)Mvel[M_Place::BL], (int)Mvel[M_Place::BR], (int)Mvel[M_Place::FR]);
  } else {
    /* 速度目標リセット */
    parts_.p_vel_interp[En_Dir::Dir_X]->reset();
    parts_.p_vel_interp[En_Dir::Dir_Y]->reset();
    parts_.p_vel_interp[En_Dir::Dir_TH]->reset();

    /* 速度制御リセット */
    parts_.p_ctrl[M_Place::FL]->reset();
    parts_.p_ctrl[M_Place::BL]->reset();
    parts_.p_ctrl[M_Place::BR]->reset();
    parts_.p_ctrl[M_Place::FR]->reset();

    /* トルク0指示 */
    parts_.p_motor[M_Place::FL]->set_CurrA_tgt(0.0f);
    parts_.p_motor[M_Place::BL]->set_CurrA_tgt(0.0f);
    parts_.p_motor[M_Place::BR]->set_CurrA_tgt(0.0f);
    parts_.p_motor[M_Place::FR]->set_CurrA_tgt(0.0f);
  }
}

void VEHICLE_CTRL::set_target_vel(Direction &_vel, Direction &_acl, Direction &_jrk) {
  parts_.p_vel_interp[En_Dir::Dir_X]->set_target_params(_vel.x, _acl.x, _jrk.x);
  parts_.p_vel_interp[En_Dir::Dir_Y]->set_target_params(_vel.y, _acl.y, _jrk.y);
  parts_.p_vel_interp[En_Dir::Dir_TH]->set_target_params(_vel.th, _acl.th, _jrk.th);
}

/**
 * @brief　車体フレームからモータフレームへの変換
 *
 * @param _Vdir : Direction 車体移動量/速度
 * @param _Mdir : float[4] モータ回転量/速度 radianベース
 */
void VEHICLE_CTRL::conv_Vdir_to_Mdir(Direction &_Vdir, float *_Mdir) {
  _Mdir[M_Place::FL] = (_Vdir.x - _Vdir.y - SQRTF2 * WHEEL_L_MM * _Vdir.th * 4.0f) / WHEEL_RADIUS_MM;
  _Mdir[M_Place::BL] = (_Vdir.x + _Vdir.y - SQRTF2 * WHEEL_L_MM * _Vdir.th * 4.0f) / WHEEL_RADIUS_MM;
  _Mdir[M_Place::BR] = (_Vdir.x - _Vdir.y + SQRTF2 * WHEEL_L_MM * _Vdir.th * 4.0f) / WHEEL_RADIUS_MM;
  _Mdir[M_Place::FR] = (_Vdir.x + _Vdir.y + SQRTF2 * WHEEL_L_MM * _Vdir.th * 4.0f) / WHEEL_RADIUS_MM;
}

/**
 * @brief モータフレームから車体フレームへの変換
 *
 * @param _Mdir : float[4] モータ回転量/速度 radianベース
 * @param _Vdir : Direction 車体移動量/速度
 */
void VEHICLE_CTRL::conv_Mdir_to_Vdir(float *_Mdir, Direction &_Vdir) {
  _Vdir.x  = (_Mdir[M_Place::FL] + _Mdir[M_Place::BL] + _Mdir[M_Place::BR] + _Mdir[M_Place::FR]) * 0.25f * WHEEL_RADIUS_MM;
  _Vdir.y  = (-_Mdir[M_Place::FL] + _Mdir[M_Place::BL] - _Mdir[M_Place::BR] + _Mdir[M_Place::FR]) * 0.25f * WHEEL_RADIUS_MM;
  _Vdir.th = (-_Mdir[M_Place::FL] - _Mdir[M_Place::BL] + _Mdir[M_Place::BR] + _Mdir[M_Place::FR]) * 0.25f / SQRTF2 / WHEEL_L_MM * WHEEL_RADIUS_MM;
}

}; // namespace VDT

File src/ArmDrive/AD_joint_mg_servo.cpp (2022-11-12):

#include <string.h>

#include "../Utility/util_mymath.hpp"
#include "AD_joint_mg_servo.hpp"

namespace ADT {

// コマンド
const uint8_t MG4005_WRITE_RAM_PID_CMD          = 0x31;
const uint8_t MG4005_SHUTDOWN_MOTOR_CMD         = 0x80;
const uint8_t MG4005_READ_MULTI_ANGLE_CMD       = 0x92;
const uint8_t MG4005_READ_MOTOR_STATE_2_CMD     = 0x9C;
const uint8_t MG4005_WRITE_TORQUE_CTRL_CMD      = 0xA1;
const uint8_t MG4005_WRITE_MULTI_POS_CTRL_2_CMD = 0xA4;

// 定数
constexpr double DB_ANG_RAW_TO_DEG = -1.0f / 100.0f / 10.0f / 256.0f; // 算術シフト分も考慮. 出力段1回転360°に変換
constexpr float  FL_ANG_DEG_TO_RAW = -100.0f * 10.0f;
constexpr float  FL_VEL_DPS_TO_RAW = -10.0f; // 減速比分のみ考慮
constexpr float  FL_CURR_DIR  = -1.0f;

// 制御パラメータ
JointMgServo::GimPosCtrlGain InitGain = {
      .fl_pg    = 0.01f,
      .fl_ig    = 0.0f,
      .fl_dg    = 0.0f,
      .fl_ilim  = 0.0f,
      .fl_lpffr = 10.0f,
};
JointMgServo::GimPosCtrlGain PosGain = {
      .fl_pg    = 0.01f,
      .fl_ig    = 0.00f,
      .fl_dg    = 0.00f,
      .fl_ilim  = 0.1f,
      .fl_lpffr = 10.0f,
};

void JointMgServo::init() {
  is_torque_on_prev = false;
  is_torque_on      = false;
  is_connected      = true;

  /* 初期化用パラメータ */
  set_myctrl_gain_params(InitGain);

  /* Pos要求 */
  set_reqmsg_multipos();
}

void JointMgServo::update() {

  if(is_torque_on_prev && !is_torque_on) {
    /* トルクON->トルクOFF遷移時 */
    // subproc_shutdown(); // shutdownはしない
    pos_ctrl_.reset();
  } else if(!is_initialized && is_torque_on) {
    /* Pos初期化されていないけどトルクON時 */
    subproc_torquectrl();
  } else if(is_torque_on) {
    /* トルクON時＆Position制御 */
    // set_myctrl_gain_params(PosGain);
    // subproc_torquectrl();
    subproc_posctrl();
  } else if(!is_torque_on){
    /* トルクOFF時＆Pos初期化時 */
    set_myctrl_gain_params(InitGain);
    subproc_torquectrl();
  }

  set_reqmsg_multipos();
  is_torque_on_prev  = is_torque_on;
  fl_pre_raw_tgt_deg = fl_raw_tgt_deg; // 目標速度用に前の速度を残しておく
}

void JointMgServo::rx_callback(MgMsgRx *rxMsg, int16_t microsec_id) {
  if(rxMsg->u8_d[0] == 0x92) {
    /* read multi-loop angle */
    uint64_t u64_ang = 0;
    for(int i = 0; i < 7; i++) {
      u64_ang = u64_ang | (rxMsg->mlt_ang.u8_ang[i] << (i * 8));
    }
    fl_raw_now_deg = (float)((double)((int64_t)(u64_ang << 8)) * DB_ANG_RAW_TO_DEG);

    /* トルクOFF時は現目標位置を現在位置で上書き */
    if(!is_torque_on) fl_raw_tgt_deg = fl_raw_now_deg;

  } else if(rxMsg->u8_d[0] == 0x9C || rxMsg->u8_d[0] == 0xA1) {
    /* summary */
    /* 電流情報の保存 */
    fl_out_now_cur = FL_CURR_DIR*(float)conv_raw_to_current((double)rxMsg->summary.s16_iq);
  }
}

void JointMgServo::subproc_shutdown() {
  /* Motor Shutdown処理 */
  MgMsgTx *p_txparams = (MgMsgTx *)tx1data;

  /* コマンド作成 */
  p_txparams->cmd_generic.u8_cmd = MG4005_SHUTDOWN_MOTOR_CMD;
  memset(p_txparams->cmd_generic.u8_dummy, 0, 7);
  is_updated_txdata1 = true;
}

void JointMgServo::subproc_torquectrl() {
  MgMsgTx *p_txparams = (MgMsgTx *)tx1data;

  /* 速度情報の作成 */
  pos_ctrl_.set_target(fl_raw_tgt_deg);
  float _fl_iq    = pos_ctrl_.update(fl_raw_now_deg);

  // 絶対角度に応じたFFトルク値 90deg → 50mA
  // 初期化されていない場合はこの演算を飛ばす
  if(is_initialized){
    _fl_iq -= 0.05f*UTIL::mymath::sinf(UTIL::mymath::deg2rad(get_now_deg()));
  }

  _fl_iq          = (_fl_iq > fl_curlim_A) ? fl_curlim_A : ((_fl_iq < -fl_curlim_A) ? -fl_curlim_A : _fl_iq);
  int16_t _s16_iq = (int16_t)(FL_CURR_DIR*conv_current_to_raw((double)_fl_iq));

  // 最終リミット(念のため)
  const int16_t C_S16_FINAL_LIM = 450;
  _s16_iq = (_s16_iq > C_S16_FINAL_LIM) ? C_S16_FINAL_LIM : ((_s16_iq < -C_S16_FINAL_LIM) ? -C_S16_FINAL_LIM : _s16_iq);


  /* コマンド作成 */
  p_txparams->iqctrl.u8_cmd       = MG4005_WRITE_TORQUE_CTRL_CMD;
  p_txparams->iqctrl.u8_dummy0[0] = 0;
  p_txparams->iqctrl.u8_dummy0[1] = 0;
  p_txparams->iqctrl.u8_dummy0[2] = 0;
  p_txparams->iqctrl.s16_iq       = _s16_iq;
  p_txparams->iqctrl.u8_dummy1[0] = 0;
  p_txparams->iqctrl.u8_dummy1[1] = 0;
  is_updated_txdata1              = true;
}

void JointMgServo::subproc_posctrl() {
  MgMsgTx *p_txparams = (MgMsgTx *)tx1data;

  /* 速度情報の作成 */
  float    fl_tgt_vel  = fabsf((fl_raw_tgt_deg - fl_pre_raw_tgt_deg) / c_params.fl_ctrl_time_s * FL_VEL_DPS_TO_RAW);
  uint16_t u16_tgt_vel = (uint16_t)((fl_tgt_vel > 1800) ? 1800 : fl_tgt_vel);

  /* コマンド作成 */
  p_txparams->posctrl2.u8_cmd      = MG4005_WRITE_MULTI_POS_CTRL_2_CMD;
  p_txparams->posctrl2.u8_dummy    = 0;
  p_txparams->posctrl2.u16_vel_lim = u16_tgt_vel;
  p_txparams->posctrl2.s32_ang     = (int32_t)(fl_raw_tgt_deg * FL_ANG_DEG_TO_RAW);
  is_updated_txdata1               = true;
}

/**
 * @brief Tx2にPosRead要求を設定
 *
 */
void JointMgServo::set_reqmsg_multipos() {
  MgMsgTx *p_txparams            = (MgMsgTx *)tx2data;
  p_txparams->cmd_generic.u8_cmd = MG4005_READ_MULTI_ANGLE_CMD;
  memset(p_txparams->cmd_generic.u8_dummy, 0, 7);
  is_updated_txdata2 = true;
}

} // namespace ADT

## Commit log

2022-04-23 add : base libraries
    [robot_controller.kicad_pcb, robot_controller.sch]
2022-04-24 feat : Imu Com (Test)
2022-05-01 fix : sch
    [robot_controller.kicad_pcb, robot_controller.sch]
2022-05-02 feat : disable LED0 ( for imu spi sck)
2022-05-02 feat : enable adc&dma for floor sensors
2022-05-02 feat : enable a kondo servo for the yaw0 joint
2022-05-04 feat : motor CAN com
2022-05-08 add : micro-ros-arduino lib (custom)
2022-05-15 fix : CAN rx msg filter masks
    [VD_can_controller.hpp]
2022-05-15 feat : get status of vehicle motors
2022-06-12 feat : setup CAN3 for a gimbal motor of pitch
2022-06-12 feat : setup CAN2 for my bldc servos
2022-06-15 feat : Arm Initialize mode
2022-06-18 fix : my servo current lim unit
    [AD_joint_mybldc_servo.cpp]
2022-06-18 fix : ics servo connection flag
    [AD_joint_ics_servo.cpp]
2022-06-18 fix : CAN mailbox status print disable
    [VD_can_controller.hpp]
2022-06-18 feat : add debug print
2022-06-18 fix : NULL ptr exception (TimeAngleMsg)
    [RM_task_main.cpp]
2022-06-19 fix : joint message order
2022-06-19 fix : variable length message of ROS
    [RM_task_main.cpp]
2022-06-22 fix : time angle command
    [AD_task_main.cpp, RM_task_main.cpp]
2022-06-22 feat : VDT motor vel control
2022-06-27 fix : time angle seq data array
    [AD_task_main.cpp]
2022-06-27 feat : vehicle velocity control
2022-06-27 fix : Jetson IP address
    [RM_task_main.cpp]
2022-06-28 feat : differential gear joint 1
2022-06-28 feat : arm servo init default function
2022-06-29 fix : my servo CAN config
2022-06-29 feat : servo can config fix
2022-06-29 fix : ADT init & reset func
    [AD_joint_ics_servo.cpp]
2022-06-29 fix : gimbal servo protocol fix
    [AD_joint_gim_servo.cpp]
2022-06-29 fix : differential gear calc fix
2022-07-02 feat : use Jetson local network
2022-07-02 feat : gimbal servo pos control by trq con
2022-07-02 feat : motor dir changable (only my servo)
2022-07-04 add ics servo stretch
2022-08-12 update : sch
    [robot_controller.kicad_pcb, robot_controller.sch]
2022-08-12 fix : vehicle speed control
    [VD_vehicle_controller.cpp]
2022-08-12 fix : delete no use include
    [main.cpp]
2022-09-18 feat : mg4005 servo motor
2022-09-18 feat : mg servo config
2022-09-19 feat : prevent time-angle cmd overlap
    [RM_task_main.cpp]
2022-09-23 fix : microros setting
    [RM_task_main.cpp]
2022-09-23 disable arm debug printf
2022-09-23 fix : case of time angle id 0
2022-10-02 disable ADT debug print
2022-10-16 feat : velocity control (const jerk)
2022-10-23 feat : vehicle motor control logger
2022-10-29 camera gimbal enable
2022-10-29 camera gimbal enable add
2022-11-02 param : camera gimbal angle
2022-11-02 feat : camera task config
2022-11-02 temp : mg servo pos con by torque instr
2022-11-05 fix : arm drive pos seq bug
2022-11-05 mg motor torque control
2022-11-06 mg servo pos con rivival
2022-11-06 camera init pitch angle update
2022-11-08 fix : vehicle rotate direction
    [VD_task_main.cpp]
2022-11-11 arm drive bug fix
    [AD_joint_ics_servo.cpp, AD_task_main.cpp]
2022-11-12 mg servo stability update
    [AD_joint_mg_servo.cpp]
2022-11-12 fix : arm control bug
    [AD_joint_ics_servo.cpp, AD_task_main.cpp, RM_task_main.cpp]
2022-11-12 update arm init pos
2022-11-12 arm log visualizer
2022-11-16 camera params update
2022-11-18 camera gimbal initialize update
2023-10-04 board update v2
    [robot_controller.kicad_pcb, robot_controller.sch]
2023-10-15 in sch updating
    [robot_controller.sch]
2023-11-19 fix vehicle order abort judgement
    [RM_task_main.cpp]
2023-11-19 VDT fix gain rot
    [VD_vehicle_controller.cpp]
2024-08-18 sch update
    [robot_controller.kicad_pcb, robot_controller.sch]
2024-09-07 feat : camera gimbal yaw
2024-11-16 add camera yaw control
2024-11-16 camera gimbal merge miss
2024-11-16 fix cam yaw
2024-11-16 floor sensor config on
2024-11-16 off debug print fdt
2024-11-17 fix floor sensor judge method and params
    [RM_task_main.cpp]
2025-06-22 fix : odom topic
    [RM_task_main.cpp]
2025-06-24 feat : double buffer for imu
2025-06-25 feat : odometry
2025-06-25 fix : gear ratio inv
    [VD_vehicle_controller.cpp]
2025-09-21 fix cmdvel topic name
    [RM_task_main.cpp]
2025-11-08 fix floor sensor flag
2025-11-15 add floor ignore switch
2025-11-15 temporary camera task off
2026-02-22 Revert "temporary camera task off"
    This reverts commit c090d6b953e579bf34f4e5df4c758a91819cbdc7.
    [RM_task_main.cpp]
2026-09-26 Enable shinai tip height correction on Teensy arm
2026-10-18 Report arm execution progress and prioritize safe aborts
